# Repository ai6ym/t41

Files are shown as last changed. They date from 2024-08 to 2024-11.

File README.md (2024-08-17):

# T41-EP SDT Project Files

Hardware and software files for the T41-EP SDT as sold / distributed by [AI6YM](https://ai6ym.radio/t41-ep-sdt). These files are branched from [K9HZ's Repo](https://github.com/DRWJSCHMIDT/T41) and [G0ORX's Repo](https://github.com/g0orx/T41-EP) with some files from the [SoftwareControlledHamRadio Groups.IO](https://groups.io/g/SoftwareControlledHamRadio).

Changes present here are minor modifications made to enable automated SMD assembly, pre-programming of the Teensy and ATTiny, etc. Refinements to various BOMs (bill of materials) have been made to substitute parts which are unavailable or correct errors.

Software within this repository is licensed under GNU GPL v3. Hardware designs are licensed under TAPR OHL Version 1.0. In addition to these licenses the original creators of the T41, Albert F Peter (AC8GY) and Dr. Jack Purdum (W8TEE), have requested that any commercial use of the designs receive their written permission.

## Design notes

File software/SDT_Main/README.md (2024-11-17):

# Introduction

This repository hosts the code for the T41-EP Software Defined Transceiver (SDT). Originally designed by Al Peter-AC8GY and Jack Purdum-W8TEE, the T41-EP is a 20W, HF, 7 band, CW/SSB Software Defined Transceiver (SDT) with features not even found in commercial radios costing ten times as much (e.g., up to 192kHz spectrum display bandwidth, ALP CW decoder, Bode Plots). The T41-EP is a self-contain SDT that does not require an external PC, laptop, or tablet to use. Al and Jack wrote a book, available on [Amazon](https://a.co/d/drLsJlJ), describing the theory and operation of the T41-EP.

### Home on the web

The T41-EP is a fully open-source radio. This repository hosts the transceiver software. The hardware designs are hosted on Bill-K9HZ's [GitHub repository](https://github.com/DRWJSCHMIDT/T41/tree/main/T41_V012_Files_01-15-24). The primary forum for discussions on the T41-EP radio is on [Groups.io](https://groups.io/g/SoftwareControlledHamRadio/topics).

### Design philosophy

The EP stands for Experimenter's Platform because the T41-EP is designed around 5 small printed circuit boards (100mm x 100mm) that can be easily swapped for boards of your own design. Because the T41-EP project is completely Open Source, you have complete access to the C/C++ source code that controls the T41-EP as well as the KiCad design files, schematics, and Gerber files. 

### Hardware purchase

The latest version (V12.6) of the bare PCBs are available for less than $5 each on the [discussion forum](https://groups.io/g/SoftwareControlledHamRadio). If you prefer a partially-assembled kit,  Justin AI6YM sells them on his [website](https://ai6ym.radio/t41-ep-sdt/).

Kits for the prior hardware version (V11) were produced and sold by the [4SQRP club](http://www.4sqrp.com/T41main.php).

### Major software variants

There are three primary software forks for the T41-EP radio. Greg KF5N has produced the [T41 Extreme Experimenters Edition (T41EEE)](https://github.com/Greg-R/T41EEE) which implements innovative features but currently only supports V11 hardware. [Terrance KN6ZDE](https://github.com/tmr4/T41_SDR) has a fork that implements mouse and keyboard input, a beacon monitor, and has implemented new modes like NFM and some data modes.

This repository hosts the "official" vanilla fork for the [V12.6 hardware](https://github.com/DRWJSCHMIDT/T41/tree/main/T41_V012_Files_01-15-24). It merges the original software written by Jack and Al with the additional features written by [John Melton-G0ORX](https://github.com/g0orx/SDTVer050.0). We aspire to merge in changes and features implemented by others if they are supported by unmodified V12.6 hardware. You are encouraged to fork this repository, experiment, and submit pull requests if you develop a feature others will like! Your help tackling the list of [Issues](https://github.com/KI3P/SDTVer050.0/issues) would also be valuable.

# SDTVer050.2

This version has the following extra software features:

* Bearing plots
* Bode plots
* Kenwood TS-2000 CAT interface
* Built-in-test for I2C errors

The V12.6 hardware features currently supported in this version include:

* Shutdown routine using the ATTiny85 on the main board
* V12.6 BPF board
* K9HZ LPF board (band select only)
* G0ORX / K9HZ MCP23017 front panel and encoders
* IQ and power amp calibration

V12.6 hardware features that still need to be supported in software include:

* K9HZ LPF SWR meter
* K9HZ LPF transverter selection
* K9HZ LPF 100W amp selection
* K9HZ LPF antenna selection

# Compiling

To build this version configure Arduino IDE to use the [Teensyduino](https://www.pjrc.com/teensy/td_download.html) library, select the Teensy 4.1 board, and select the following build configuration options: 

* Tools->Optimize->Faster with LTO
* Tools->USB Type->Dual Serial
* Tools->CPU Speed->528 MHz

The memory Usage with these options set and both `G0ORX_FRONTPANEL` and `G0ORX_CAT` enabled should look something like:

```
   FLASH: code:274516, data:93624, headers:8684   free for files:7749640
   RAM1: variables:200864, code:256936, padding:5208   free for local variables:61280
   RAM2: variables:454272  free for malloc/new:70016
```

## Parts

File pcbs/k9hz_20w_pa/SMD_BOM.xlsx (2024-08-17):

 |  |  | xxxx xxxx xxxxx xxPCS BOM (Sample Bill of Materials)
Item # | *Designator | *Qty | Manufacturer | *Mfg Part # | Description / Value | *Package/Footprint | Type | Your Instructions / Notes
1 | C1 | 1 | KEMET | C1206C470K5GACTU | CAP CER 47pf 50V X7R 1206 | 1206 | SMD
2 | C2, C3, C4, C5, C9, C10, C12, C13, C14, C15, C17, C20, C21, C23, C25 | 15 | KEMET | C1206C104K5RAC7867 | CAP CER 0.1UF 50V X7R 1206 | 1206 | SMD
3 | C7, C8, C16, C19 | 4 | KEMET | C1206C103K5RACTM | CAP CER 0.01UF 50V X7R 1206 | 1206 | SMD
4 | C18 | 1 | Yageo | CC1206MRY5V9BB105 | CAP CER 1uF 50V Y5V 1206 20% | 1206 | SMD
5 | C6, C11 | 2 | Samsung Electro-Mechanics | CL31A106KBHNNNE | CAP CER 10 UF 50V X7R 1206 | 1206 | SMD
6 | C22 | 1 | KEMET | EEV107M035A9HAA | Alum CAP SMD 35V 100uF 20% | 9H | SMD
7 | Q1 | 1 | Infineon Technologies | IRLML9301TRPBF | IRLML9301TRPBF | SOT-23-3 | SMD
8 | Q4 | 1 | Comchip Technology | MMBT3904-HF | MMBT3904 SOT-23 | SOT-23-3 | SMD
9 | R10, R11 | 2 | Yageo | RC1206FR-075R1L | SMD 5.1 Ohms 250 mW 1206 1% | 1206 | SMD
10 | R1 | 1 | Yageo | RC1206FR-076R8L | SMD 6.8 Ohms 250 mW 1206 1% | 1206 | SMD
11 | R4, R5 | 2 | SEI Stackpole | RMCF1206FT100R | SMD 100 Ohms 250 mW 1206 1% | 1206 | SMD
12 | R2, R3 | 2 | Vishay / Dale | CRCW1206680RFKEAC | SMD 680 Ohms 250 mW 1206 1% | 1206 | SMD
13 | R12, R13 | 2 | SEI Stackpole | RMCF1206FT750R | SMD 750 Ohms 250 mW 1206 1% | 1206 | SMD
14 | R8, R9, R14, R15, R16, R17, R18, R19, R23 | 9 | Yageo | RC1206FR-071KL | SMD 1000 Ohms 250 mW 1206 1% | 1206 | SMD
15 | R6, R7 | 2 | Bourns | CR1206-FX-2201ELF | SMD 2.2K Ohms 250 mW 1206 1% | 1206 | SMD
16 | R22, R24 | 2 | Welwyn Components / TT Electronics | WCR1206-10KFA | SMD 10K Ohms 250 mW 1206 1% | 1206 | SMD
17 | U1 | 1 | Texas Instruments | OPA2674ID | OPA2674ID | SOIC-8 | SMD
18 | U2 | 1 | STMicroelectronics | L78L09ACUTR | L78L09ACUTR | SOT-89 | SMD
Need a quick and accurante quote? Need an efficient production? Please read SMT Ordering Necessary Files & Info in 1 minute. Thank you very much! (https://www.pcbway.com/smt_ordering_guide.html)
Click for Instructions on How to Create a BOM (https://www.pcbway.com/blog/PCB_Assembly/How_to_Build_a_BOM__Bill_Of_Materials_.html)

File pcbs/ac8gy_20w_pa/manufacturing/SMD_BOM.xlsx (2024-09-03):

 |  |  | xxxx xxxx xxxxx xxPCS BOM (Sample Bill of Materials)
Item # | *Designator | *Qty | Manufacturer | *Mfg Part # | Description / Value | *Package/Footprint | Type | Your Instructions / Notes
1 | C1, C2, C3, C5, C6, C7, C8, C9, C10, C12, C24, C101, C102, C104, C105, C107, C108, C109, C110, C111, C112, C201, C202, C204, C206, C208, C209, C300, C302 | 29 | KEMET | C1206C104K5RAC7800 | CAP CER 0.1UF 50V X7R 1206 | 1206 | SMD
2 | L1 | 1 | Abracon LLC | AIML-1206-R18K-T | FIXED IND 180NH 250MA 300MOHM SM | 1206 | SMD
3 | L2, L101, L103, L201, L204 | 5 | Eaton - Electronics Division | MCLA3216V1-2R2-R | FIXED IND 2.2UH 50MA 500MOHM SMD | 1206 | SMD
4 | L102, L104, L202, L203 | 4 | Vishay / Dale | ILSB1206ERR33K | FIXED IND 330NH 250MA 600MOHM SMD | 1206 | SMD
5 | R101, R103 | 2 | TE Connectivity Passive Product | CRG1206F100R | RES SMD 100 OHM 1% 1/4W 1206 | 1206 | SMD
6 | R106, R107 | 2 | Stackpole Electronics Inc | RMCF1206FT1K10 | RES 1.1K OHM 1% 1/4W 1206 | 1206 | SMD
7 | R201, R204 | 2 | TE Connectivity Passive Product | CRGCQ1206F56R | RES 56 OHM 1% 1/4W 1206 | 1206 | SMD
8 | R303 | 1 | Stackpole Electronics Inc | RMCF1206FT470R | RES 470 OHM 1% 1/4W 1206 | 1206 | SMD
9 | R306 | 1 | TE Connectivity Passive Product | CRG1206F220R | RES 220 OHM 1% 1/4W 1206 | 1206 | SMD
10 | C4 | 1 | Yageo | CC1206KRX7R9BB391 | CAP CER 390PF 50V C0G/NP0 1206 | 1206 | SMD
11 | C103, C106, C203, C207 | 4 | Samsung Electro-Mechanics | CL31B474KBHNNNE | CAP CER 0.47UF 50V X7R 1206 | 1206 | SMD
12 | C205 | 1 | Würth Elektronik | 885012008040 | CAP CER 33PF 50V C0G/NP0 1206 | 1206 | SMD
13 | C11, C301 | 2 | Chemi-Con | EMVE160ARA101MF55G | CAP ALUM 100UF 20% 16V 4.3X4.3 SMD | 6.3x6.6mm | SMD
14 | R1 | 1 | Stackpole Electronics Inc | RMCF1206FT4K70 | RES 4.7K OHM 1% 1/4W 1206 | 1206 | SMD
15 | R2 | 1 | Rohm Semiconductor | KTR18EZPF5101 | RES SMD 5.1K OHM 1% 1/4W 1206 | 1206 | SMD
16 | R3 | 1 | Stackpole Electronics Inc | RMCF1206FT200R | RES 200 OHM 1% 1/4W 1206 | 1206 | SMD
17 | R4, R16, R304 | 3 | Stackpole Electronics Inc | RMCF1206FT150R | RES 150 OHM 1% 1/4W 1206 | 1206 | SMD
18 | R5 | 1 | Stackpole Electronics Inc | RMCF1206FT3K30 | RES 3.3K OHM 1% 1/4W 1206 | 1206 | SMD
19 | R6 | 1 | Stackpole Electronics Inc | RMCF1206FT5K60 | RES 5.6K OHM 1% 1/4W 1206 | 1206 | SMD
20 | R7 | 1 | Bourns | CR1206-FX-1201ELF | RES 1.2K OHM 1% 1/4W 1206 | 1206 | SMD
21 | R8 | 1 | Stackpole Electronics Inc | RMCF1206JT68R0 | RES 68 OHM 5% 1/4W 1206 | 1206 | SMD
22 | R9 | 1 | Stackpole Electronics Inc | RMCF1206FT3K00 | RES 3K OHM 1% 1/4W 1206 | 1206 | SMD
23 | R10 | 1 | Stackpole Electronics Inc | RMCF1206JT680R | RES 680 OHM 5% 1/4W 1206 | 1206 | SMD
24 | R11, R13 | 2 | Stackpole Electronics Inc | RMCF1206FT24K0 | RES 24K OHM 1% 1/4W 1206 | 1206 | SMD
25 | R12, R15, R301, R302 | 4 | Stackpole Electronics Inc | RMCF1206FT10K0 | RES 10K OHM 1% 1/4W 1206 | 1206 | SMD
26 | R14 | 1 | Stackpole Electronics Inc | RMCF2512JT47R0 | RES 47 OHM 1% 1/4W 1206 | 1206 | SMD
27 | R17 | 1 | Rohm Semiconductor | KTR18EZPF37R4 | RES 37.4 OHM 1% 1/4W 1206 | 1206 | SMD
28 | R19 | 1 | Yageo | RC1206FR-075K49L | RES 5.49K OHM 1% 1/4W 1206 | 1206 | SMD
Need a quick and accurante quote? Need an efficient production? Please read SMT Ordering Necessary Files & Info in 1 minute. Thank you very much! (https://www.pcbway.com/smt_ordering_guide.html)
Click for Instructions on How to Create a BOM (https://www.pcbway.com/blog/PCB_Assembly/How_to_Build_a_BOM__Bill_Of_Materials_.html)

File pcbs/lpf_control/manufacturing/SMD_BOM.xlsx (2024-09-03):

 |  |  | xxxx xxxx xxxxx xxPCS BOM (Sample Bill of Materials)
Item # | *Designator | *Qty | Manufacturer | *Mfg Part # | Description / Value | *Package/Footprint | Type | Your Instructions / Notes
1 | C15 | 1 | KEMET | C1206C102K5RAC | 1000pF 50V | 1206 | SMD
2 | C24, C25 | 2 | KEMET | C1206C301F1HACAUTO | 300 pF 50V | 1206 | SMD
3 | C14, C16 | 2 | KEMET | C1206C162K3HACTU | 1600 pF 50V | 1206 | SMD
4 | L1, L2 | 2 | Vishay / Dale | ILSB1206ER3R3K | 3.3uH | 1206 | SMD
5 | C1, C2, C3, C4, C5, C6, C7, C8, C10, C11, C12, C13, C17, C18, C20, C21, C22, C23, C128, C129, C130, C138, C140, C141, C148, C137, C139, C150, C151, C152 | 30 | KEMET | C1206C104K5RACTU | 0.1uF 50V | 1206 | SMD
6 | C19 | 1 | Kyocera AVX | 12065C153KAT2A | 15nF 50V | 1206 | SMD
7 | C132, C133, C135, C136, C146 | 5 | Samsung Electro-Mechanics | CL31B105KBHNNNE | 1uF 50V SMD 1206 Capacitor | 1206 | SMD
8 | C143, C145 | 2 | KEMET | C1206C106K4PACTU | 10uF 16V SMD 1206 Capacitor | 1206 | SMD
9 | L36, L37, L39, L41 | 4 | Laird Perfomance Materials | HZ1206E601R-10 | FB SMD 1206 600 Ohm 1A | 1206 | SMD
10 | L200 | 1 | Murata Electronics | 1264EY-100M=P3 | 10uH 20% Power Inductor | 2424 | SMD
11 | R7 | 1 | Vishay / Dale | CRCW120610K0FKEA | 10K Ohm SMD 1206 Resistor | 1206 | SMD
12 | R1, R2, R3, R12, R14, R15 | 6 | Bourns | CR1206-JW-222ELF | 2.2K Ohm SMD 1206 Resistor | 1206 | SMD
13 | U1, U3, U7, U8, U21 | 5 | MACOM | MASWSS0179TR-3000 | MASWSS0179 | SOT-26 | SMD
14 | U2 | 1 | Toshiba | 74HC237D(BJ) | 74HC237 | SOIC-16 | SMD
15 | U4, U9, U10 | 3 | Texas Instruments | ULN2803CDWR | ULN2803A | SOIC-20 | SMD
16 | U5, U6, U22 | 3 | Texas Instruments | SN74LVC1G04DCKR | 74LVC1G04DCKR | SC70-5 | SMD
17 | U12 | 1 | Texas Instruments | CD74HC4514M96 | CD74HC4514M96 | SOIC-24 | SMD
18 | U15 | 1 | Microchip Technology | MCP23017-E/SO | MCP23017_SO | SOIC-28 | SMD
19 | U18 | 1 | Microchip Technology | TC4428ACOA | TC4428 | SOIC-8 | SMD
20 | C144, C155 | 2 | KEMET | C1206C103K5RAC7210 | 10nF 50V | 1206 | SMD
21 | C147, C154 | 2 | KEMET | C1206C100J5GAC | 10pF 50V | 1206 | SMD
22 | L38, L40, L42, L43 | 4 | Abracon | AISC-1206-22NJ-T | 22nH SMD 1206 Inductor | 1206 | SMD
23 | R13, R21 | 2 | Yageo | RC1206FR-0752R3L | 52.3 Ohm SMD 1206 Resistor | 1206 | SMD
24 | R16, R18, R24, R25 | 4 | Vishay / Dale | CRCW120654R9FKEA | 54.9 Ohm SMD 1206 Resistor | 1206 | SMD
25 | R17, R22 | 2 | Vishay / Dale | CRCW1206499RFKEB | 499 Ohm SMD 1206 Resistor | 1206 | SMD
26 | U14, U19 | 2 | Analog Devices | AD8307ARZ-RL7 | AD8307 | SOIC-8 | SMD
27 | U17 | 1 | Texas Instruments | REF3440IDBVR | REF3440IDBVR | SOT-23-6 | SMD
28 | U20 | 1 | Analog Devices | AD7991YRJZ-0500RL7 | AD7991YRJZ | SOT-23-8 | SMD
Need a quick and accurante quote? Need an efficient production? Please read SMT Ordering Necessary Files & Info in 1 minute. Thank you very much! (https://www.pcbway.com/smt_ordering_guide.html)
Click for Instructions on How to Create a BOM (https://www.pcbway.com/blog/PCB_Assembly/How_to_Build_a_BOM__Bill_Of_Materials_.html)

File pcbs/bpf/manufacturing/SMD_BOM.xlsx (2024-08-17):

 |  |  | xxxx xxxx xxxxx xxPCS BOM (Sample Bill of Materials)
Item # | *Designator | *Qty | Manufacturer | *Mfg Part # | Description / Value | *Package/Footprint | Type | Your Instructions / Notes
1 | C2, C4, C5, C6, C7, C8, C9, C10, C11, C12, C13, C14, C15, C16, C17, C18, C19, C20, C21, C22, C23, C24, C25, C26, C27 C41, C90, C91, C97, C98, C100, C101,C107, C108, C190, C191, C197, C198, C200, C201, C207, C208, C290, C291, C297, C298, C300, C301, C307, C308, C400, C401, C407, C408, C500, C501, C507, C508, C600, C601, C607, C608, C700, C701 | 64 | KEMET | C1206C104K5RACTU | 0.1uF 50V SMD 1206 Capacitor | 1206 | SMD
2 | C94 | 1 | Kyocera AVX | 12061C562JAT2A | 5.6nF 50V | 1206 | SMD
3 | C104 | 1 | Kyocera AVX | 12062A302JAT2A | 3.0nF 50V | 1206 | SMD
4 | C194 | 1 | Kyocera AVX | 12065C242JAT4A | 2.4nF 50V | 1206 | SMD
5 | C204 | 1 | KEMET | C1206C202K5HACTU | 2.0nF 50V | 1206 | SMD
6 | C102, C106, C294 | 3 | KEMET | C1206C182K1RACTU | 1.8nF 50V | 1206 | SMD
7 | C92, C92b1, C96, C96b1 | 4 | KEMET | C1206C162K3HACTU | 1.6nF 50V | 1206 | SMD
8 | C304 | 1 | KEMET | C1206C132J1GACTU | 1.3nF 50V | 1206 | SMD
9 | C192, C196, C202, C206 | 4 | KEMET | C1206C122J5GACTU | 1.2nF 50V | 1206 | SMD
10 | C292, C296 | 2 | KEMET | C1206C102K5RACTU | 1.0nF 50V | 1206 | SMD
11 | C302, C306 | 2 | KEMET | C1206C751J5GACTU | 750pF 50V | 1206 | SMD
12 | C404 | 1 | Walsin | 1206B681K500CT | 680pF 50V | 1206 | SMD
13 | C504 | 1 | KEMET | C1206C511J5HACAUTO | 510pF 50V | 1206 | SMD
14 | C402, C406 | 2 | KEMET | C1206C391K1HACTU | 390pF 50V | 1206 | SMD
15 | C93, C95 | 2 | KEMET | C1206C331J5GACTU | 330pF 50V | 1206 | SMD
16 | C103, C105, C502, C506 | 4 | KEMET | C1206C301J5GACTU | 300pF 50V | 1206 | SMD
17 | C93b1, C95b1 | 2 | Kyocera AVX | 12061A251FAT2A | 250pF 50V | 1206 | SMD
18 | C602, C606 | 2 | KEMET | C1206C241J5GACTU | 240pF 50V | 1206 | SMD
19 | C604b1 | 1 | KEMET | C1206C201J5HACAUTO | 200pF 50V | 1206 | SMD
20 | C203, C205, C604 | 3 | KEMET | C1206C181J1GACTU | 180pF 50V | 1206 | SMD
21 | C193b1, C195b1 | 2 | KEMET | C1206C121J5GAC | 120pF 50V | 1206 | SMD
22 | C94b1, C194b1, C294b1 | 3 | KEMET | C1206C101K1GACTU | 100pF 50V | 1206 | SMD
23 | C303, C305, C193, C195 | 4 | Kyocera AVX | 12065A750JAT2A | 75pF 50V | 1206 | SMD
24 | C293, C295 | 2 | KEMET | C1206C680J5HACTU | 68pF 50V | 1206 | SMD
25 | C403, C405 | 2 | KEMET | C1206C510J5HACTU | 51pF 50V | 1206 | SMD
26 | C503, C505 | 2 | KEMET | C1206C430J5GACTU | 43pF 50V | 1206 | SMD
27 | C603, C605 | 2 | KEMET | C1206C130F1HACTU | 13pF 50V | 1206 | SMD
28 | R1, R2, R3, R4, R5, R6, R7, R8 | 8 | Bourns | CR1206-FX-2201ELF | 2.2K Ohm SMD 1206 Resistor | 1206 | SMD
29 | D1, D2, D3, D4 | 4 | Nexperia | BAS70H,115 | BAS70H,115 Diodes | SOD-123F-2 | SMD
30 | L1 | 1 | Murata Electronics | 1264EY-100M=P3 | 10uH SMD Incurtor | 2424 | SMD
31 | L2 | 1 | Laird Performance Materials | HZ1206E601R-10 | Ferrite Bead SMD 1206 600 Ohm | 1206 | SMD
32 | U35 | 1 | Microchip Technology | MCP23017-E/SO | MCP23017-E/SO | SOIC-28 | SMD
33 | U1, U3, U4, U6, U7, U9, U10, U12, U13, U15, U16, U18, U19, U21, U24, U25, U27, U28, U30, U31, U36 | 21 | MACOM | MASWSS0179TR-3000 | MASWS0179 | SOT-26 | SMD
34 | U2, U5, U8, U11, U14, U17, U20, U23, U26, U29, U37 | 11 | Texas Instruments | SN74LVC1G04DCKR | 74LVC1G04GW | SC70-5 | SMD
Need a quick and accurante quote? Need an efficient production? Please read SMT Ordering Necessary Files & Info in 1 minute. Thank you very much! (https://www.pcbway.com/smt_ordering_guide.html)
Click for Instructions on How to Create a BOM (https://www.pcbway.com/blog/PCB_Assembly/How_to_Build_a_BOM__Bill_Of_Materials_.html)

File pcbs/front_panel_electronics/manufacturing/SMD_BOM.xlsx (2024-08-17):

 |  |  | xxxx xxxx xxxxx xxPCS BOM (Sample Bill of Materials)
Item # | *Designator | *Qty | Manufacturer | *Mfg Part # | Description / Value | *Package/Footprint | Type | Your Instructions / Notes
1 | C1, C2 | 2 | KEMET | C1206C104K5RACTU | 0.1uF 50V 1206 SMD Capacitor | 1206 | SMD
2 | R1, R2,R3,R4 | 4 | Bourns | CR1206-FX-2201ELF | 2.2K Ohm 1206 SMD Resistor | 1206 | SMD
3 | R5, R6 | 2 | Bourns | CR1206-JW-331ELF | 330 Ohm 1206 SMD Resistor | 1206 | SMD
4 | U1, U2 | 2 | Microchip Technology | MCP23017-E/SO | MCP23017SO SOIC-28 | SOIC-28 | SMD
Need a quick and accurante quote? Need an efficient production? Please read SMT Ordering Necessary Files & Info in 1 minute. Thank you very much! (https://www.pcbway.com/smt_ordering_guide.html)
Click for Instructions on How to Create a BOM (https://www.pcbway.com/blog/PCB_Assembly/How_to_Build_a_BOM__Bill_Of_Materials_.html)

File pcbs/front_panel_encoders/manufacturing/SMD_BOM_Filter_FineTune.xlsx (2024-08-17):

 |  |  | xxxx xxxx xxxxx xxPCS BOM (Sample Bill of Materials)
Item # | *Designator | *Qty | Manufacturer | *Mfg Part # | Description / Value | *Package/Footprint | Type | Your Instructions / Notes
1 | C1, C2, C3, C4, C5, C6 | 6 | KEMET | C1206C104K5RACTU | 0.1uF 50V 1206 SMD Capacitor | 1206 | SMD
2 | R3, R5, R7, R8 | 4 | Vishay / Dale | CRCW12060000Z0EAC | 0 Ohm SMD 1206 Resistor | 1206 | SMD
Need a quick and accurante quote? Need an efficient production? Please read SMT Ordering Necessary Files & Info in 1 minute. Thank you very much! (https://www.pcbway.com/smt_ordering_guide.html)
Click for Instructions on How to Create a BOM (https://www.pcbway.com/blog/PCB_Assembly/How_to_Build_a_BOM__Bill_Of_Materials_.html)

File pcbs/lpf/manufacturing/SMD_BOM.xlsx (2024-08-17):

 |  |  | xxxx xxxx xxxxx xxPCS BOM (Sample Bill of Materials)
Item # | *Designator | *Qty | Manufacturer | *Mfg Part # | Description / Value | *Package/Footprint | Type | Your Instructions / Notes
1 | C70 | 1 | Murata Electronics | GQM2195C2E140JB12D | 14pF 200V | 0805 | SMD
2 | C63, C69 | 2 | YAGEO | CC1206JKNPOCBN270 | 27pF 200V | 1206 | SMD
3 | C65 | 1 | YAGEO | CC1206JKNPOCBN330 | 33pF 200V | 1206 | SMD
4 | C71 | 1 | KEMET | C1206C390J2GACTU | 39 pF 200V | 1206 | SMD
5 | C60, C62, C64 | 3 | YAGEO | CC1206JRNPOABN470 | 47pF 200V | 1206 | SMD
6 | C57, C75 | 2 | KEMET | C1206C560J2GACTU | 56pF 200V | 1206 | SMD
7 | C39, C67, C100 | 3 | Kyocera AVX | 12062A600FAT2A | 60pF 200V | 1206 | SMD
8 | C66, C68 | 2 | KEMET | C1206C680J2GACTU | 68pF 200V | 1206 | SMD
9 | C24, C35, C41, C53, C72, C85, C90, C105 | 8 | KEMET | C1206C820J2GACTU | 82pF 200V | 1206 | SMD
10 | C51, C82 | 2 | Cal-Chip Electronics Inc. | CHV1206N500910JCT | 91pF 200V | 1206 | SMD
11 | C32, C38, C52, C56, C58, C74, C76, C94, C99 | 9 | Kyocera AVX | 12062A101JAT2A | 100pF 200V | 1206 | SMD
12 | C37, C98 | 2 | Kyocera AVX | 12062A121JAT2A | 120pF 200V | 1206 | SMD
13 | C27, C28, C33, C36, C42, C61, C83, C95, C97, C102, C104 | 11 | YAGEO | CC1206JRNPOABN151 | 150pF 200V | 1206 | SMD
14 | C50, C81 | 2 | Kyocera AVX | 12062A181JAT2A | 180pF 200V | 1206 | SMD
15 | C34, C49, C80, C96 | 4 | Kyocera AVX | 12062A221JAT2A | 220pF 200V | 1206 | SMD
16 | C25, C43, C44, C48, C54, C55, C59, C73, C77, C79, C87, C88, C103 | 13 | Kyocera AVX | 12062A331JAT2A | 330pF 200V | 1206 | SMD
17 | C26, C101 | 2 | Kyocera AVX | 12062A391JAT2A | 390pF 200V | 1206 | SMD
18 | C30, C40, C47, C78, C89, C92 | 6 | Yageo | CC1206JRNPOABN471 | 470pF 200V | 1206 | SMD
19 | C31, C93 | 2 | KEMET | C1206C561J2GACTU | 560pF 200V | 1206 | SMD
20 | C46, C86 | 2 | Kyocera AVX | 12062A122JAT2A | 1200pF 200V | 1206 | SMD
21 | C29, C91 | 2 | YAGEO | CC1206JRNPOABN152 | 1500pF 200V | 1206 | SMD
22 | C45, C84 | 2 | Kyocera AVX | 12062C222JAT2A | 2200pF 200V | 1206 | SMD
23 | C106, C107, C108, C109, C110, C111, C112, C113, C114, C115, C116, C117, C118, C119, C120, C121, C122, C123, C124, C125, C126, C127, C157, C158 | 24 | KEMET | C1206C104K5RACTU | 0.1uF 50V | 1206 | SMD
Need a quick and accurante quote? Need an efficient production? Please read SMT Ordering Necessary Files & Info in 1 minute. Thank you very much! (https://www.pcbway.com/smt_ordering_guide.html)
Click for Instructions on How to Create a BOM (https://www.pcbway.com/blog/PCB_Assembly/How_to_Build_a_BOM__Bill_Of_Materials_.html)

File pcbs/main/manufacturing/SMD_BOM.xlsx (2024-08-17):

 |  |  | xxxx xxxx xxxxx xxPCS BOM (Sample Bill of Materials)
Item # | *Designator | *Qty | Manufacturer | *Mfg Part # | Description / Value | *Package/Footprint | Type | Your Instructions / Notes
1 | C2, C3, C8, C9, C10, C11, C13, C14, C16, C19, C20, C23, C24, C26, C31 | 15 | KEMET | C1206C104K5RACTU | 0.1uF 50V SMD 1206 Ceramic Capacitor | 1206 | SMD
2 | C32, C34 | 2 | KEMET | C1206C222K5RAC | 2.2nF 50V SMD 1206 Capacitor | 1206 | SMD
3 | C28, C29 | 2 | KEMET | C1206C225K5R | 2.2uF 25V SMD 1206 Capacitor | 1206 | SMD
4 | C4, C12, C15, C17, C18, C21, C22, C25, C27, C30, C33 | 11 | KEMET | C1206C106K4P | 10uF 16V SMD 1206 Capacitor | 1206 | SMD
5 | D2, D3, D4 | 3 | Dialight | 599-0220-007F | LED Diodes SMD; Colors to suit | 1206 | SMD
6 | L1, L2, L3 | 3 | Murata Electronics | 1264EY-100M=P3 | Inductor 10uH 20% | 2424 | SMD
7 | R6, R11, R12 | 3 | Bourns | CR1206-FX-1000ELF | 100 Ohm SMD 1206 Resistor | 1206 | SMD
8 | R15 | 1 | YAGEO | RC1206JR-07150RL | 150 Ohm SMD 1206 Resistor | 1206 | SMD
9 | R4, R5 | 2 | TE Connectivity / Holsworthy | CRGCQ1206J220R | 220 Ohm SMD 1206 Resistor | 1206 | SMD
10 | R8, R9, R14 | 3 | SEI Stackpole | RMCF1206FT330R | 330 Ohm SMD 1206 Resistor | 1206 | SMD
11 | R10, R13 | 2 | Vishay / Dale | CRCW1206470RJNEAC | 470 Ohm SMD 1206 Resistor | 1206 | SMD
12 | R7 | 1 | Vishay / Dale | CRCW12062K20JNEAC | 2.2K Ohm SMD 1206 Resistor | 1206 | SMD
13 | U5 | 1 | Texas Instruments | PCM5102APWR | PCM5102APW Stereo DAC TSSOP-20 |  | SMD
14 | U6 | 1 | Texas Instruments | PCM1808PWR | PCM1808PWR Stereo ADC TSSOP-14 |  | SMD
15 | C5 | 1 | Samsung Electro-Mechanics | CL31B105KBHNNNE | 1.0uF 50V SMD 1206 Capacitor | 1206 | SMD
16 | D1 | 1 | Diodes Incorporated | S1A-13-F | S1A-13-F Diode or equivalent (1N4001) |  | SMD
17 | R3 | 1 | Vishay / Dale | CRCW12061K00JNEAC | 1K Ohm SMD 1206 Resistor | 1206 | SMD
18 | R1, R2 | 2 | Vishay / Dale | CRCW120610K0FKEB | 10K Ohm SMD 1206 Resistor | 1206 | SMD
Need a quick and accurante quote? Need an efficient production? Please read SMT Ordering Necessary Files & Info in 1 minute. Thank you very much! (https://www.pcbway.com/smt_ordering_guide.html)
Click for Instructions on How to Create a BOM (https://www.pcbway.com/blog/PCB_Assembly/How_to_Build_a_BOM__Bill_Of_Materials_.html)

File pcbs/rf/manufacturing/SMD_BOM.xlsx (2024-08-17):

 |  |  | xxxx xxxx xxxxx xxPCS BOM (Sample Bill of Materials)
Item # | *Designator | *Qty | Manufacturer | *Mfg Part # | Description / Value | *Package/Footprint | Type | Your Instructions / Notes
1 | C1, C3, C11, C12, C14, C32, C35, C36, C39, C41, C42, C48, C51, C57, C60, C67, C71 | 17 | Kyocera AVX | 12065D106KAT2A | 10uF 50V SMD 1206 Capacitor | 1206 | SMD
2 | C2, C9, C15, C24 | 4 | Samsung Electro-Mechanics | CL31B105KBHNNNE | 1uF 50V SMD 1206 Capacitor | 1206 | SMD
3 | C4, C10, C17, C28, C37, C54 | 6 | KEMET | C1206C103K5RAC7210 | 10nF 50V SMD 1206 Capacitor | 1206 | SMD
4 | C5, C21 | 2 | Kyocera AVX | 12065C101KAT2A | 100pF 50V SMD 1206 Capacitor | 1206 | SMD
5 | C8, C19 | 2 | Walsin | 1206B181K160CT | 180pF 50V SMD 1206 Capacitor | 1206 | SMD
6 | C6, C7, C13, C16, C18, C20, C22, C23, C25, C26, C27, C29, C30, C31, C40, C43, C45, C47, C49, C52, C53, C55, C56, C58, C59, C61, C62, C63, C64, C65, C66, C68, C70, C72, C73, C80 | 36 | KEMET | C1206C104K5RACTU | 0.1uF 50V SMD 1206 Capacitor | 1206 | SMD
7 | C33, C46 | 2 | KEMET | C1206C222K5RAC | 2.2nF 50V SMD 1206 Capacitor | 1206 | SMD
8 | C34, C38, C44, C50 | 4 | Kyocera AVX | 12065C204KAT4A | 0.2uF 50V SMD 1206 Capacitor | 1206 | SMD
9 | L1, L2, L3, L5, L6, L7, L8, L9, L107 | 9 | Laird Performance Materials | HZ1206E601R-10 | FB SMD 1206 600 Ohm 1A | 1206 | SMD
10 | L4, L10 | 2 | Murata Electronics | LQM31PN1R5M00L | 1.5uH SMD 1206 Inductor | 1206 | SMD
11 | L11, L12, L13 | 3 | Murata Electronics | 1264EY-100M=P3 | 10uH 20% SMD Inductor | 6.3mm x 6.3mm | SMD
12 | R1, R13 | 2 | Panasonic | ERA-8AEB202V | 2K Ohm SMD 1206 Resistor | 1206 | SMD
13 | R2, R3, R5, R6, R10, R11, R17, R18 | 8 | Bourns | CR1206-JW-512ELF | 5.1K Ohm SMD 1206 Resistor | 1206 | SMD
14 | R4, R8, R16, R22, R54 | 5 | Bourns | CR1206-FX-1000ELF | 100 Ohm SMD 1206 Resistor | 1206 | SMD
15 | R7, R9, R12, R20, R21, R23, R24, R28, R30, R39, R44, R47, R53, R55 | 14 | Bourns | CR1206-JW-103ELF | 10K Ohm SMD 1206 Resistor | 1206 | SMD
16 | R14 | 1 | Vishay / Dale | CRCW120636R5FKEA | 36.5 Ohm SMD 1206 Resistor | 1206 | SMD
17 | R15, R19 | 2 | Bourns | CR1206-FX-5100ELF | 510 Ohm SMD 1206 Resistor | 1206 | SMD
18 | R25, R29, R32, R36, R41, R46 | 6 | Bourns | CR1206-FX-1002ELF | 10K Ohm 1% SMD 1206 Resistor | 1206 | SMD
19 | R26, R34, R49, R50, R51, R52, R60, R61, R62, R63 | 10 | Vishay / Dale | CRCW12062K20JNEAC | 2.2K Ohm SMD 1206 Resistor | 1206 | SMD
20 | R27, R33, R38, R43 | 4 | Vishay / Dale | CRCW120649R9FKEAC | 49.9 Ohm 1% SMD 1206 Resistor | 1206 | SMD
21 | R31, R45 | 2 | Bourns | CR1206-FX-2201ELF | 2.2K Ohm 1% SMD 1206 Resistor | 1206 | SMD
22 | R35, R37 | 2 | Vishay / Dale | CRCW12063K30FKEA | 3.3K Ohm SMD 1206 Resistor | 1206 | SMD
23 | R40, R42 | 2 | Vishay / Dale | CRCW12060000Z0EAC | 0 Ohm SMD 1206 Resistor | 1206 | SMD
24 | R48, R73 | 2 | Vishay / Dale | CRCW1206100KFKEAC | 100K Ohm SMD 1206 Resistor | 1206 | SMD
25 | R56 | 1 | Bourns | CR1206-FX-1801ELF | 1.8K Ohm SMD 1206 Resistor | 1206 | SMD
26 | R57 | 1 | Bourns | CR1206-FX-3300ELF | 330 Ohm SMD 1206 Resistor | 1206 | SMD
27 | R58 | 1 | Bourns | CR1206-FX-5102ELF | 51K Ohm SMD 1206 Resistor | 1206 | SMD
28 | R59 | 1 | Bourns | CR1206-FX-1201ELF | 1.2K Ohm SMD 1206 Resistor | 1206 | SMD
29 | U1, U4 | 2 | Texas Instruments | SN74CBTLV3253DR | 74CBTLV3253DR in SOIC-16 | 16-SOIC | SMD
30 | U2 | 1 | Mini-Circuits | PSA-8A+ | PSA-8A+ | CA1389 | SMD
31 | U3, U12 | 2 | pSemi | PE4312C-Z | PE4312 (or DAT-31R5A-PP+) | QFN-20 | SMD
32 | U5, U10 | 2 | Texas Instruments | SN74LVC1G04DCKR | 74LVC1G04DCKR | SC70-5 | SMD
33 | U6, U8, U106, U107 | 4 | Texas Instruments | MC33078DR | MC33078 | SOIC-8 | SMD
34 | U16 | 1 | Texas Instruments | LM358BIDR | LM358B | SOIC-8 | SMD
35 | U7, U9 | 2 | Macom | MASWSS0179TR-3000 | MASWSS0179 | SOT-26 | SMD
36 | U11 | 1 | Skyworks Solutions, Inc. | SI5351A-B-GT | Si5351A-B-GT | MSOP-10 | SMD
37 | U13 | 1 | Mini-Circuits | MAR-3SM+ | MAR-3SM+ | WW107 | SMD
38 | U17 | 1 | Texas Instruments | LM317LIDR | LM317LIDR | SOIC-8 | SMD
39 | U21 | 1 | Microchip Technology | MCP23017-E/SO | MCP23017_SO | SOIC-28 | SMD
40 | TR1 | 1 | Mini-Circuits | ADT1-1+ | ADT1-1+ | CD542 | SMD
41 | TR2 | 1 | Mini-Circuits | ADT2-1T+ | ADT2-1T+ | CD542 | SMD
42 | Y1 | 1 | ECS | ECS-TXO53-S3-33-250-BN-TR | ECS-TX053-S3 | 5.0 x 3.2 mm | SMD
43 | Y2 | 1 | ECS | ECS-250-18-5PX-GM-TR | 25MHz | SPX | SMD
Need a quick and accurante quote? Need an efficient production? Please read SMT Ordering Necessary Files & Info in 1 minute. Thank you very much! (https://www.pcbway.com/smt_ordering_guide.html)
Click for Instructions on How to Create a BOM (https://www.pcbway.com/blog/PCB_Assembly/How_to_Build_a_BOM__Bill_Of_Materials_.html)

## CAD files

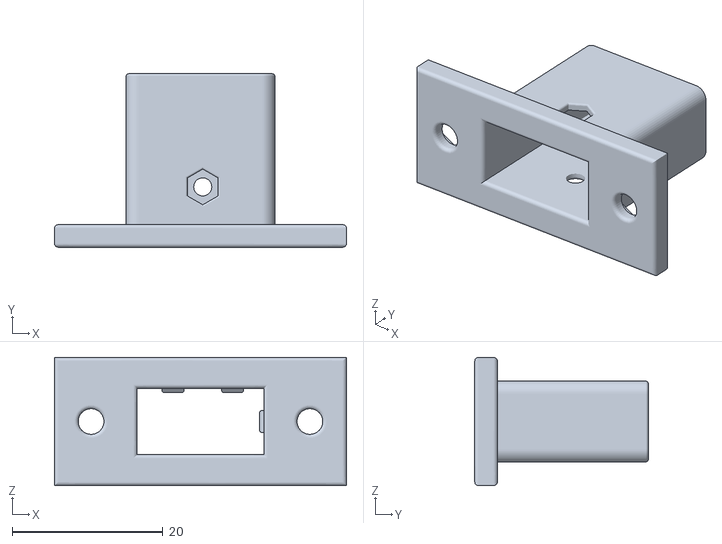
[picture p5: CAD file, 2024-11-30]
enclosure/manufacturing/Powerpole Panel Mount.stl
38.7 x 23.0 x 17.0

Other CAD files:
enclosure/Powerpole Panel Mount.f3d

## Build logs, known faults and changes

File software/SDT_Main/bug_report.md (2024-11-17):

---
name: Bug report
about: Create a report to help us improve
title: ''
labels: ''
assignees: ''

---

**Describe the bug**
A clear and concise description of what the bug is.

**To Reproduce**
Steps to reproduce the behavior:
1. Press button '...'
2. Spin dial '....'
3. See error

**Expected behavior**
A clear and concise description of what you expected to happen.

**Affected radio board**
Which board or system component the issue affects and its version number. e.g., V12 RF board, Teensy output audio.

**Desktop environment (if relevant for error):**
 - OS: [e.g. Windows]
 - Arduino IDE version [e.g. 2.3.3]

**Additional context**
Add any other context about the problem here.

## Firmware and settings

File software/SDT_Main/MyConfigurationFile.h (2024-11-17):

//==============================================================
// This file is used to configure the specifics of your radio by 
// commenting/uncommenting/modifying particular #define statements
// to select which hardware you installed and any modifications to
// their addresses. You can also select which extra software capa-
// bilities you want to include in the same way. If you need to re-
// map Teensy pins or change the operation of the front panel buttons
// please edit SDT.h
//==============================================================

//====================== Hardware selections ===================

// Select either V11 hardware or V12 hardware
//#define V11HWR   // Selectes Si5351 clock frequencies for the 4x frequency method           
#define V12HWR     // Selects the V12 BPF, K9HZ LPF, V12 RF control, and affects Si5351

#ifdef V12HWR
  // Set the I2C addresses of the LPF, BPF, and RF boards
  #define K9HZ_LPF_MCP23017_ADDR  0x25
  #define BPF_MCP23017_ADDR       0x24
  #define RF_MCP23017_ADDR        0x27

  // K9HZ LPF options
  // Uncomment the appropriate line below to select which power detection option 
  // you populated in the SWR meter
  #define K9HZ_LPF_SWR_LOG_AMP
  //#define K9HZ_LPF_SWR_DIODE

  // Uncomment the appropriate line below to select which detected power readout 
  // option you populated in the SWR meter
  #define K9HZ_LPF_SWR_AD7991
  //#define K9HZ_LPF_SWR_ANALOG
#endif //V12HWR

// You can't change the Si5351 address, but it sometimes differs from the default 
// of 0x60. Change it here if needed.
#define SI5351_BUS_BASE_ADDR    0x60

// Uncomment if using G0ORX or K9HZ MCP23017 Front Panel
#define G0ORX_FRONTPANEL

// Set the I2C addresses of the front panel board
#define G0ORX_PANEL_MCP23017_ADDR_1 0x20
#define G0ORX_PANEL_MCP23017_ADDR_2 0x21

// Pick one of the following encoder configurations
#define                           NORM_ENCODER                              // Leave as is UNLESS...
//#define                           FOURSQRP                                // ...you are using the 4 States QRP kit

//====================== Software selections ===================

// Uncomment to exclude BEARING and/or BODE code
//#define EXCLUDE_BEARING
//#define EXCLUDE_BODE

// Uncomment if using G0ORX Kenwood TS-2000 CAT interface
#define G0ORX_CAT

// G0ORX_AUDIO_DISPLAY draws a Time Domain plot of the Microphone when transmitting
#define G0ORX_AUDIO_DISPLAY

// Fast tune function on fine tune knob from Harry Brash GM3RVL
#define FAST_TUNE

//====================== User Specific Preferences =============

#define DEBUG 		                1                                         // Uncommented for debugging, comment out for normal use
#define DECODER_STATE							0						                              // 0 = off, 1 = on
#define DEFAULT_KEYER_WPM   			15                                        // Startup value for keyer wpm
#define FREQ_SEP_CHARACTER  			'.'					                              // Some may prefer period, space, or combo
#define MAP_FILE_NAME   					"Cincinnati.bmp"                          // Name you gave to BMP map file. Max is 50 chars
#define MY_LAT										39.07466                                  // Coordinates for QTH
#define MY_LON										-84.42677
#define MY_CALL										"AI6YM"                                   // Default max is 10 chars
#define MY_TIMEZONE          			"PST: "                                   // Default max is 10 chars
//DB2OO, 29-AUG-23: TIME_24H to display 24 hour times (Utility.cpp). If this is not defined 12h display will be used
#define TIME_24H                  1
//DB2OO, 29-AUG-23: ITU_REGION to determine band borders: Upper band limits on 80m (3.8MHz vs 4.0MhHz) and 40m (7.2MHz vs. 7.3MHz)
// #define ITU_REGION                1  //for Europe
#define ITU_REGION                  2   // for USA
//#define ITU_REGION    3   // Asia/Oceania
// DB2OO, 29.823:. Analog Signal on this pin will be used for an analog S-Meter (250uA full scale) connected via 10kOhm to this output. 1uF capacitor paralle to the S-Meter. --> Display.cpp. 
// This might conflict with other hardware modifications, that might use Pin 33 for a different purpose --> please check, before defining this
//#define HW_SMETER              33
// DB2OO, 30-AUG-23: with TCVSDR_SMETER (TCVSDR=Teensy Convolution SDR) defined the S-Meter bar will be consistent with the dBm value and it will not go over the box for S9+40+
#define TCVSDR_SMETER             1
//DB2OO, 10-SEP-23: TCXO_25MHZ defined sets the default EEPROMData.freqCorrectionFactor = 0, as the TCXO is supposed to deliver 25.00000MHz
//#define TCXO_25MHZ                1

#define PADDLE_FLIP								0						                              // 0 = right paddle = DAH, 1 = DIT
#define STRAIGHT_KEY_OR_PADDLES		0						                              // 0 = straight, 1 = paddles
#define SDCARD_MESSAGE_LENGTH     3000L                                     // The number of milliseconds to leave error message on screen
//#define SD_CARD_PRESENT         0                                         //   JJP  7/18/23

//====================== System specific ===============
#define CURRENT_FREQ_A            7200000                                   // VFO_A
#define CURRENT_FREQ_B            7030000                                   // VFO_B
#define DEFAULTFREQINCREMENT 		  4                                         // Default: (10, 50, 100, 250, 1000, 10000Hz)
#define DEFAULT_POWER_LEVEL       10                                        // Startup power level. Probably 20 for most people
#define FAST_TUNE_INCREMENT    	  1			 		                                // Default from above for fine tune
#define SPLASH_DELAY              1000L                                     // How long to show Splash screen. Use 1000 for testing, 4000 normally
#define BIT_DELAY_LONG            10000L                                    // How long to show BIT screen with errors
#define BIT_DELAY_SHORT           1000L                                     // How long to show BIT screen when no error
#define STARTUP_BAND        			BAND_40M                                  // This is the 40M band. see around line 575 in SDT.h // G0ORX changed from 1

#define CENTER_SCREEN_X           400
#define CENTER_SCREEN_Y           245
#define IMAGE_CORNER_X            190                                       // ImageWidth = 378 Therefore 800 - 378 = 422 / 2 = 211
#define IMAGE_CORNER_Y            40                                        // ImageHeight = 302 Therefore 480 - 302 = 178 / 2 = 89
#define RAY_LENGTH                190

//=========== Applying hardware/software selections ============

// Set multiplication factors for your QSD and QSE boards.
#ifdef NORM_ENCODER
  #define MASTER_CLK_MULT_RX 2
  #define MASTER_CLK_MULT_TX 2  
#else
  #define MASTER_CLK_MULT_RX 4
  #define MASTER_CLK_MULT_TX 4
#endif 

#if defined(G0ORX_FRONTPANEL)
#include "G0ORX_FrontPanel.h"
#endif // G0ORX_FRONTPANEL

#if defined(G0ORX_CAT)
#include "G0ORX_CAT.h"
#endif // G0ORX_CAT

#ifdef V12HWR
  #define K9HZ_LPF           // Selects the K9HZ LPF board
  #define V12BPF             // Selects the V12 BPF board
#endif //V12HWR

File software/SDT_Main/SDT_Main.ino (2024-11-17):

/*********************************************************************************************

  This comment block must appear in the load page (e.g., main() or setup()) in any source code
  that uses code presented as whole or part of the T41-EP source code.

  (c) Frank Dziock, DD4WH, 2020_05_8
  "TEENSY CONVOLUTION SDR" substantially modified by Jack Purdum, W8TEE, and Al Peter, AC8GY

  This software is made available under the GNU GPLv3 license agreement. If commercial use of this
  software is planned, we would appreciate it if the interested parties contact Jack Purdum, W8TEE, 
  and Al Peter, AC8GY.

  Any and all other uses, written or implied, by the GPLv3 license are forbidden without written 
  permission from from Jack Purdum, W8TEE, and Al Peter, AC8GY.

V050.2 10-17-26 Al Peter,AC8GY
  Extensively revised the Process2 File to allow Calibrate using the V12.6 hardware. This file is
  included as ProcessV12.cpp given the scope of its modifications.
    1. Requires the 12.6 version RF board with the Cal jumper installed
    2. Both Input and Output Attenuators must be installed and active.
    3. No external calble are required. Simply short the Cal jumpers during the Receive and Xmit I/Q calibration sessions.
    4. Calibration values are stored in EEPROM.

V050.1 10/17/24 Oliver King, KI3P
  1. Added support for V12 features:
  1.1 Shutdown routine
  1.2 K9HZ LPF board control (band select only)
  1.3 V12 BPF board control
  1.4 Teensy pin assignment changes
  1.5 Built-in test to check I2C connections on start
  2. Merged in John Melton G0ORX's changes for new band definitions, JSON, RF control

V050.0 7/4/24  Jack Purdum, W8TEE
  1. Sectivated SELECT button to end Bode Plot
  2. Removed a number of redundant variables and uncalled functions.
  3. Comment out manu Serial.print() calls that the user may want to restore, but not toggle with DEBUG
  4. Fixed minor bug in Bearing code
  FLASH: code:261352, data:127580, headers:8376   free for files:7729156
   RAM1: variables:244000, code:257272, padding:4872   free for local variables:18144
   RAM2: variables:377120  free for malloc/new:147168

V049.7_Bode_04_03_24 Al Peter AC8GY
  1. Added Bode plot Module to allow easy evaluation of T41 BP and LP Filters.
  2. Intended for plotting of frequency response of T41 Filters. 
  3. Frequency range 3.5MHz to over 50MHz
  4. V12 hardware only.
  5. Code changes marked as "//=================== AFP 03-30-24 V012 Bode Plot"
  6. Most additions/changes are in a  new File "BodePlotter.cpp"
  7. Uses CW output as input to filter DUT.
  8. Connect DUT out directly to V12 RF board input
  9. Either use V12 input Attenuator set at -30dB or add external 30dB 50ohm atten. Take care to not overload RF input.
  10. Use full CW output  value for best SN.
  11. Disconnect RF PA and do not use other fT41 Filters during test.
  12. If testing T41 Filter boards, Band+ and Band- can be used to select bands.
  13. User buttons are employed as follows:
    * User1 (15) saves the current Bode plot as reference
    * User2 (16) toggles display of reference plot
    * User3 (17) toggles display of US Ham bands on plot
    * User4 (18) exits Bode routine.
  15. Encoders are used as follows:
    * FineTune changes the upper stop frequency
    * CenterTune changes the start frequency
    * Filter encoder activates ans moves the con-screen cursor
    * th=The Vol encoder sets the amount of offset of the plot displayed in 1dB increments. iseful for determining insertion loss.
  15. A Reference plot can be shown along with current plot. Useful for adjusting filter component values duing test.
  16. An on-screen cursor can be activated using the Filter encoder. Cursor values are display on screen.
  17. Plot frequency limits can be dynamically set during Bode Plot operation:
    * Center Tune Encoder changes the Bode plot Start frequency
    * Fine Tune encoder changes the stop frequency.
  18. The plot amplitude can be adjust using the Vol encoder. Increments are 1dB at a time.

v049.6a Mar 13, 2024 Jack Purdum, W8TEE
  1. Added ability to cancel out of Main Menu by pressing switch 18
v049.6 Mar 11, 2024 Jack Purdum, W8TEE
  1. Changed the menu system to use the Spectrum-Waterfall area of the display to show both Main and
     Secondary menu choices.
  2. Modified Menu/Filter encoder to work with new menu system
  3. Removed redundant buttons from switch matrix.
  4. Reordered switches to reflect new menu. This frees up 4 switches that can be reassigned by the user.
     The suggested switches are coded for the positions:
      
      Select    Memus     Band +

      Zoom      Display   Band -
                 Reset

      Mode      Demod     Main
                        Increment

      Noise     Notch   Fine Tune  
                        Increment

      Filter      CW      User 1
      Adjust     Reset  

      User 2    User 3    User 4

  5. Expanded information in Info Window
  6. Fixed display code to reflect changes.
  FLASH: code:251344, data:127580, headers:9168   free for files:7738372
   RAM1: variables:206272, code:247272, padding:14872   free for local variables:55872
   RAM2: variables:368928  free for malloc/new:155360

V049.3 October XX, 2023 Greg Raven (KF5N)
  1. Fixed muting after calibration.
  2. Minor comment edits.
  3. Fixed mic compression bug which caused default to -15 dB.
  4. Added ITU Region 3.
  5. The transmit equalizer has a default profile based on Neville's testing for SSB voice.
  6. SSB transmit compression defaults changed to Neville's settings.
  7. Morse decode will print last character and then a space.

V049.2 October 16, 2023 Greg Raven (KF5N)
  1. Changed folder to SDT and file to SDT.ino.
  2. Mic compression indicator fixed.
  3. Updates to fix remaining paddle flip issues.
  4. Mic compressor fixes.
  5. CW sidetone adjustment via encoder.
  6. Changed volume control to logarithmic.
  7. Changed instances of currentBandA to currentBand in CW Excite.
  8. Removed Serial print statement.
  9. Removed Serial print statements from volume control.
 10. Increased audio memory to 450.
 11. Working sidetone adjust with encoder.
 12. Perfect log responding volume control for sidetone.
 13. Inserted G0ORX main loop efficiency improvement.  Si5351 CLK2 is now set to PLLB.
 14. John G0ORX AGC enhancements.
 15. AGC updates.
 16. Fixed minor problem with RX/TX indicator showing TX coming out of setup().
 17. Added defines for ITU_REGION and TIME24H for internationalization. (DB2OO)
 18. S-Meter bar aligned to dBm value (DB2OO)
 19. Fixed override of EEPROM defaults in EEPROMRead(). (DB2OO)
 20. Jack changed encoder pins for 4SQRP.
 21. Changed ENCODER3_ENCODER_A/B to FINETUNE_ENCODER_A/B.
 22. Updated SetBandRelay() function to toggle only necessary GPOs.
 23. Fixed receiver outage after sidetone adjust.  Sidetone default = 50.0
 24. S-Meter: added debug code and rfGainAllBands (DB2OO)
 25. Add additional debug info in DisplaydbM() (DB2OO)
 26. Removed attribute DMAMEM from audioSpectBuffer because it breaks the S-meter.
 27. Added Jack's code to change color of version when running 4SQRP.
 28. Deleted increment variable in Encoders.cpp.  Was causing a compile warning.
 29. ITU_REGION set to 2, TCXO_25MHZ undefined, DEBUG_SMETER undefined.
 30. Added comments to ITU_REGION.
 31. Updated changes list in SDT.ino.  Added macro to increment variable in Encoders.cpp to eliminate warning.

V049.1 Aug 21, 2023 Greg Raven (KF5N)
  1. Changed 3 instances of VFO_A to activeVFO in function ButtonFrequencyEntry().
  2. Added TxRxFreq = centerFreq to EEPROMRead() to fix frequency related bugs.
  3. Added clean-up code to CopySDtoEEPROM() in function EEPROMOptions().
  4. Fixes for calibration graphics.
  5. Changed 2 instances of currentFreqA to currentFreq in ResetTuning() function.
  6. Previous fix to CopySDToEEPROM() accidentally overwritten.  This puts it back.
  7. Reactivated text in Direct Frequency Entry.
  8. Replaced keyer symbolic constants with appropriate global variables.
  9. Removed call to CopyEEPROMToSD() from EEPROMStartup().
 10. Bypass paddle flip in the case of a straight key.
 11. Frequency overwrite, Bearing, exit, and Direct Entry updates.
 12. Fixed receive cal not saving, cal graphics, SSB power cal.
 13. Revised RX cal again because it was saving 1X zoom.
 14. Restored option for KD0RC switch matrix calibration code.
 15. A significant refactoring of calibration.
 16. Fix for keyer click-clack.
 17. Keyer lower limit 5 WPM.
 18. Decoder was modifying keyer WPM.

V049a Aug 06, 2023, 2023 Jack Purdum (W8TEE)
  1. Corrected paddle flip issue
  2. Made several changes to set sdCardPresent to the proper value when tested.
  3. Changed frequency display to account for new font.
  4. Raised the frequencies by 2 pixels as the new font made then display too low and affect band info
  5. If only 1 map file found, no longer asks you to pick. It selects automatically the one file.
  FLASH: code:244340, data:123488, headers:8996   free for files:7749640
   RAM1: variables:206304, code:240792, padding:21352   free for local variables:55840
   RAM2: variables:342944  free for malloc/new:181344

V049 Aug 03, 2023, 2023 Jack Purdum (W8TEE)
  1. Numerous UI and formating fixes
  FLASH: code:243636, data:123488, headers:8676   free for files:7750664
   RAM1: variables:206304, code:240088, padding:22056   free for local variables:55840
   RAM2: variables:342944  free for malloc/new:181344

V048g July 31, 2023 Jack Purdum (W8TEE)
  1. If you have multiple QTH files for the bearing feature, it did not clear screen properly. Fixed.
  2. CW filter graphics managed between mode, band, and VFO changes.
  3. Several tuning fixes by Greg (KF5N)
  FLASH: code:243572, data:123488, headers:8740   free for files:7750664
   RAM1: variables:206304, code:240024, padding:22120   free for local variables:55840
   RAM2: variables:342944  free for malloc/new:181344

V048e July 30, 2023 Jack Purdum (W8TEE)
  1. Really made EEPROMSaveDefaults2() the function to initialize the EEPROM struct
  2. Noise filters were not completely erased in all cases after a change. Fixed.
  3. Fixed overrun of spectrum floor if a negative number entered.
  4. If you have multiple QTH files for the bearing feature, it did not clear screen properly. Fixed.
  FLASH: code:246388, data:123488, headers:8996   free for files:7747592
   RAM1: variables:206304, code:242840, padding:19304   free for local variables:55840
   RAM2: variables:342944  free for malloc/new:181344

V048d July 29, 2023 Jack Purdum (W8TEE)
  1. Made EEPROMSaveDefaults2() the function to initialize the EEPROM struct
  FLASH: code:246260, data:123488, headers:9124   free for files:7747592
   RAM1: variables:206304, code:242712, padding:19432   free for local variables:55840
   RAM2: variables:342944  free for malloc/new:181344

V048c July 28, 2023 Jack Purdum (W8TEE)
  1. Removed string literals for EEPROM switch values from EEPROMToSD() function call.
  2. Reformatted the EEPROMShow() output.
  FLASH: code:246388, data:123488, headers:8996   free for files:7747592
   RAM1: variables:206304, code:242840, padding:19304   free for local variables:55840
   RAM2: variables:342944  free for malloc/new:181344

V048b July 28, 2023 Jack Purdum (W8TEE)
  1. More bug fixes by Greg, mainly in the EEPROM code.
  FLASH: code:242804, data:123488, headers:8484   free for files:7751688
   RAM1: variables:206304, code:239256, padding:22888   free for local variables:55840
   RAM2: variables:342944  free for malloc/new:181344

V048a July 27, 2023 Jack Purdum (W8TEE)
  1. FIxed EEPROMWrite() bug.
  FLASH: code:249780, data:131680, headers:8676   free for files:7736328
   RAM1: variables:214496, code:246232, padding:15912   free for local variables:47648
   RAM2: variables:342944  free for malloc/new:181344

V048 July 26, 2023 Jack Purdum (W8TEE)
  1. Integrated Greg's display and encoder changes
  2. Fixed the EEPROM to SD copy routine
  FLASH: code:249780, data:131680, headers:8676   free for files:7736328
   RAM1: variables:214496, code:246232, padding:15912   free for local variables:47648
   RAM2: variables:342944  free for malloc/new:181344
  
V047k July 22, 2023 Greg KF5N
  1. Update to calibration for improved button response.
  2. Added additional improvements for audio quality.
  3. Added user settable noise floor by band feature.
  4. Implemented fix for VFO relay switching bug.
  5. Fixed EEPROM so separator character displays correctly on EEPROM/SD dump
  FLASH: code:239700, data:131680, headers:8516   free for files:7746568
   RAM1: variables:214496, code:236152, padding:25992   free for local variables:47648
   RAM2: variables:342944  free for malloc/new:181344  
   
V047i July 18, 2023 Jack Purdum (W8TEE)
  1. Removed SD_CARD_PRESENT and set global sdCardPresent by call to SDPresentCheck() 
  FLASH: code:237972, data:134128, headers:8820   free for files:7745544
   RAM1: variables:214496, code:234424, padding:27720   free for local variables:47648
   RAM2: variables:342944  free for malloc/new:181344

V047h July 17, 2023 Jack Purdum (W8TEE)
  1. EEPROM Cancel option was not shown on secondary menu.
  2. currentFrreqA and currentFreqB now properly stored in EEPROM when Saved.
  FLASH: code:233556, data:132040, headers:9180   free for files:7751688
   RAM1: variables:212384, code:230008, padding:32136   free for local variables:49760
   RAM2: variables:342944  free for malloc/new:181344
  
V047g July 17, 2023 Jack Purdum (W8TEE)
  1. Move several constants to MyConfigurationFile.h and rearranged them
  2. Increased Splash delay to 4 seconds
  FLASH: code:233556, data:132040, headers:9180   free for files:7751688
   RAM1: variables:212384, code:230008, padding:32136   free for local variables:49760
   RAM2: variables:342944  free for malloc/new:181344

V047f July 15, 2023 Jack Purdum (W8TEE)
  1. Change ShowFrequency() and FormatFrequency() to properly align digits
  2. Fixed EEPROM sync indicator for main tune changes
  3. Commented clearScreen function call in DrawBandWidthIndicatorBar() to clean up audio. KF5N
  4. DMAMEM attribute added to TX equalizer buffers to free up stack space. KF5N
  5. Consolidated Si5351 start-up code into setup() function. KF5N
  6. Revised waterfall.  User needs to adjust noise level (pixels above axis) to just above bottom of spectrum display. KF5N
  FLASH: code:237076, data:134064, headers:8756   free for files:7746568
   RAM1: variables:228832, code:233528, padding:28616   free for local variables:33312
   RAM2: variables:328544  free for malloc/new:195744

Vo47e July 15, 2023 Jack Purdum (W8TEE)
  1. Changed the font to use the onboard font for frequency display
  2. Change SHowFrequency() and FormatFrequency() to accommodate new font.
  FLASH: code:237012, data:134064, headers:8820   free for files:7746568
   RAM1: variables:228832, code:233464, padding:28680   free for local variables:33312
   RAM2: variables:328544  free for malloc/new:195744
 
V047c July 14, 2023 Jack Purdum (W8TEE)
  1. Merged Greg's latest code with Jack's. The main difference is the calibration and bearing code, plus the new header file.
  2. Main tuning fixed
  3. Missing dB scale added back and prints correctly now
  FLASH: code:236820, data:134064, headers:9012   free for files:7746568
   RAM1: variables:228832, code:233272, padding:28872   free for local variables:33312
   RAM2: variables:328544  free for malloc/new:195744

V047b July 13, 2023 Jack Purdum (W8TEE)
  1. FIxed the "waterfall stripe" per Greg email.
  FLASH: code:232980, data:144160, headers:8900   free for files:7740424
   RAM1: variables:227808, code:229432, padding:32712   free for local variables:34336
   RAM2: variables:328544  free for malloc/new:195744
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
FASTRUN void loop()  // Replaced entire loop() with Greg's code  JJP  7/14/23
{
  int pushButtonSwitchIndex = -1;

  long ditTimerOff;  //AFP 09-22-22
  long dahTimerOn;

#if defined(G0ORX_CAT)
  CATSerialEvent();
#endif

  // KI3P: Check for signal to begin shutdown and perform shutdown routine if requested
  if (digitalRead(BEGIN_TEENSY_SHUTDOWN) == HIGH){
    ShutdownTeensy();
  }

  valPin = ReadSelectedPushButton();  // Poll UI push buttons
  if (valPin != BOGUS_PIN_READ) {     // If a button was pushed...

//    Serial.print("\nIn loop() top: valPin = ");
//    Serial.println(valPin);
    pushButtonSwitchIndex = ProcessButtonPress(valPin);  // Winner, winner...chicken dinner!
//    Serial.print("pushButtonSwitchIndex = ");
//    Serial.println(pushButtonSwitchIndex);
    ExecuteButtonPress(pushButtonSwitchIndex);
    //Serial.print("   mainMenuIndex = " );
    //Serial.print(mainMenuIndex);
    //Serial.print("   secondaryMenuIndex = " );
    //Serial.println(secondaryMenuIndex);
  }



  //  State detection
#if defined(G0ORX_FRONTPANEL) || defined(G0ORX_CAT)
  if (xmtMode == SSB_MODE && my_ptt == HIGH) radioState = SSB_RECEIVE_STATE;
  if (xmtMode == SSB_MODE && my_ptt == LOW) radioState = SSB_TRANSMIT_STATE;
#else
  if (xmtMode == SSB_MODE && digitalRead(PTT) == HIGH) radioState = SSB_RECEIVE_STATE;
  if (xmtMode == SSB_MODE && digitalRead(PTT) == LOW) radioState = SSB_TRANSMIT_STATE;
#endif // G0ORX_FRONTPANEL
  if (xmtMode == CW_MODE && (digitalRead(paddleDit) == HIGH && digitalRead(paddleDah) == HIGH)) radioState = CW_RECEIVE_STATE;  // Was using symbolic constants. Also changed in code below.  KF5N August 8, 2023
  if (xmtMode == CW_MODE && (digitalRead(paddleDit) == LOW && xmtMode == CW_MODE && keyType == 0)) radioState = CW_TRANSMIT_STRAIGHT_STATE;
  if (xmtMode == CW_MODE && (keyPressedOn == 1 && xmtMode == CW_MODE && keyType == 1)) radioState = CW_TRANSMIT_KEYER_STATE;
  if (lastState != radioState) {
    SetFreq();  // Update frequencies if the radio state has changed.
  }
  //lastState = radioState;  // G0ORX 01092023

  //  Begin radio state machines

  //  Begin SSB Mode state machine

  switch (radioState) {
    case (SSB_RECEIVE_STATE):
      if (lastState != radioState) {  // G0ORX 01092023
        #if !defined(V12HWR)
        digitalWrite(MUTE, LOW);      // KI3P, no MUTE function in V12
        #endif
        modeSelectInR.gain(0, 1);
        modeSelectInL.gain(0, 1);
        digitalWrite(RXTX, LOW);  //xmit off
        #ifdef V12HWR
        setBPFPath(BPF_IN_RX_PATH);
        currentRF_InAtten = RAtten[currentBand];
        SetRF_InAtten(currentRF_InAtten);
        #endif
        T41State = SSB_RECEIVE;
        xrState = RECEIVE_STATE;
        modeSelectInR.gain(0, 1);
        modeSelectInL.gain(0, 1);
        modeSelectInExR.gain(0, 0);
        modeSelectInExL.gain(0, 0);
        modeSelectOutL.gain(0, 1);
        modeSelectOutR.gain(0, 1);
        modeSelectOutL.gain(1, 0);
        modeSelectOutR.gain(1, 0);
        modeSelectOutExL.gain(0, 0);
        modeSelectOutExR.gain(0, 0);
        phaseLO = 0.0;
        barGraphUpdate = 0;
        if (keyPressedOn == 1) {
          return;
        }
        ShowTransmitReceiveStatus();
      }
      ShowSpectrum();
      break;
    case SSB_TRANSMIT_STATE:
      Q_in_L.end();  //Set up input Queues for transmit
      Q_in_R.end();
      Q_in_L_Ex.begin();
      Q_in_R_Ex.begin();
      comp1.setPreGain_dB(currentMicGain);
      comp2.setPreGain_dB(currentMicGain);
      if (compressorFlag == 1) {
        SetupMyCompressors(use_HP_filter, (float)currentMicThreshold, comp_ratio, attack_sec, release_sec);  // Cast currentMicThreshold to float.  KF5N, October 31, 2023
      } else {
        if (compressorFlag == 0) {
          SetupMyCompressors(use_HP_filter, 0.0, comp_ratio, 0.01, 0.01);
        }
      }
      xrState = TRANSMIT_STATE;
      // centerTuneFlag = 1;  Not required with revised tuning scheme.  KF5N July 22, 2023
      #if !defined(V12HWR)
      digitalWrite(MUTE, HIGH);  // KI3P, no MUTE function in V12
      #else
      digitalWrite(XMIT_MODE, XMIT_SSB); // KI3P, July 28, 2024
      setBPFPath(BPF_IN_TX_PATH);
      currentRF_OutAtten = XAttenSSB[currentBand] + getPowerLevelAdjustmentDB();
      if (currentRF_OutAtten > 63) currentRF_OutAtten = 63;
      if (currentRF_OutAtten < 0) currentRF_OutAtten = 0;
      SetRF_OutAtten(currentRF_OutAtten);
      #endif
      digitalWrite(RXTX, HIGH);  //xmit on
      xrState = TRANSMIT_STATE;
      modeSelectInR.gain(0, 0);
      modeSelectInL.gain(0, 0);
      modeSelectInExR.gain(0, 1);
      modeSelectInExL.gain(0, 1);
      modeSelectOutL.gain(0, 0);
      modeSelectOutR.gain(0, 0);
      modeSelectOutExL.gain(0, powerOutSSB[currentBand]);  //AFP 10-21-22
      modeSelectOutExR.gain(0, powerOutSSB[currentBand]);  //AFP 10-21-22
      ShowTransmitReceiveStatus();

#if defined(G0ORX_FRONTPANEL) || defined(G0ORX_CAT)
      while (my_ptt == LOW) {
#else
      while (digitalRead(PTT) == LOW) {
#endif // G0ORX_FRONTPANEL
        ExciterIQData();
#if defined(G0ORX_FRONTPANEL)
        ExecuteButtonPress(ProcessButtonPress(ReadSelectedPushButton()));
#endif // G0ORX_FRONTPANEL
#if defined(G0ORX_CAT)
        CATSerialEvent();
#endif // G0ORX_CAT
      }
      Q_in_L_Ex.end();  // End Transmit Queue
      Q_in_R_Ex.end();
      Q_in_L.begin();  // Start Receive Queue
      Q_in_R.begin();
      xrState = RECEIVE_STATE;
      break;
    default:
      break;
  }
  //======================  End SSB Mode =================

  // Begin CW Mode state machine
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

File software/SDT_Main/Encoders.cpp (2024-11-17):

#ifndef BEENHERE
#include "SDT.h"
#endif

#ifdef FAST_TUNE
// Fine frequency tune control with variable speed by Harry Brash GM3RVL
bool FastTune = true;    //  HMB
uint32_t FT_last_time;   // millis() of last fine tune step   HMB
bool FT_ON = false;      // In fast tunung mode HMB
int FT_step_counter = 0; // how many fast steps have there been continuously HMB
int last_FT_step_size = 1; // so can go back HMB
const unsigned long FT_on_ms = 30;  // time between FTsteps below which increases the step size
const unsigned long FT_cancel_ms = 400;  // time between steps above which FT is cancelled
const int FT_trig = 4;  // number of short steps to trigger fast tune,
const int FT_step = 500;  // Hz step in Fast Tune
unsigned long MS_temp;    // HMB
unsigned long FT_delay;   // HMB
#endif // FAST_TUNE

/*****
  Purpose: EncoderFilter

  Parameter list:
    void

  Return value;
    void
    Modified AFP21-12-15
*****/
void FilterSetSSB() {
  long filter_change;

  // SSB
  if (filter_pos != last_filter_pos) {
    tft.writeTo(L2);  // Clear layer 2.  KF5N July 31, 2023
    tft.clearMemory();
    if (xmtMode == CW_MODE) BandInformation();
    tft.fillRect((MAX_WATERFALL_WIDTH + SPECTRUM_LEFT_X) / 2 - filterWidth, SPECTRUM_TOP_Y + 17, filterWidth, SPECTRUM_HEIGHT - 20, RA8875_BLACK);  // Erase old filter background
    filter_change = (filter_pos - last_filter_pos);
    if (filter_change >= 1) {
      filterWidth--;
      if (filterWidth < 10)
        filterWidth = 10;
    }
    if (filter_change <= -1) {
      filterWidth++;
      if (filterWidth > 100)
        filterWidth = 50;
    }
    last_filter_pos = filter_pos;
    // =============  AFP 10-27-22
    switch (bands[currentBand].mode) {
      case DEMOD_LSB:
        if (switchFilterSideband == 0)  // "0" = normal, "1" means change opposite filter
        {
          bands[currentBand].FLoCut = bands[currentBand].FLoCut + filter_change * 50 * ENCODER_FACTOR;
          //fHiCutOld= bands[currentBand].FHiCut;
          FilterBandwidth();
        } else if (switchFilterSideband == 1) {
          //if (abs(bands[currentBand].FHiCut) < 500) {
          bands[currentBand].FHiCut = bands[currentBand].FHiCut + filter_change * 50 * ENCODER_FACTOR;
          fLoCutOld = bands[currentBand].FLoCut;
        }
        break;
      case DEMOD_USB:
        if (switchFilterSideband == 0) {
          bands[currentBand].FHiCut = bands[currentBand].FHiCut - filter_change * 50 * ENCODER_FACTOR;
          //bands[currentBand].FLoCut= fLoCutOld;
          FilterBandwidth();
        } else if (switchFilterSideband == 1) {
          bands[currentBand].FLoCut = bands[currentBand].FLoCut - filter_change * 50 * ENCODER_FACTOR;
          // bands[currentBand].FHiCut= fHiCutOld;
        }
        break;
      case DEMOD_AM:
        bands[currentBand].FHiCut = bands[currentBand].FHiCut - filter_change * 50 * ENCODER_FACTOR;
        bands[currentBand].FLoCut = -bands[currentBand].FHiCut;
        FilterBandwidth();
        InitFilterMask();
        break;
      case DEMOD_SAM:  // AFP 11-03-22
        bands[currentBand].FHiCut = bands[currentBand].FHiCut - filter_change * 50 * ENCODER_FACTOR;
        bands[currentBand].FLoCut = -bands[currentBand].FHiCut;
        FilterBandwidth();
        InitFilterMask();
        break;
    }
    // =============  AFP 10-27-22
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

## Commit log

2024-08-17 Initial commit of hardware files as used in manufacturing.
    [SMD_BOM.xlsx, SMD_BOM_Filter_FineTune.xlsx, SMD_BOM_Tune_Volume.xlsx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]
2024-09-03 Replacing K9HZ amplifier with updated AC8GY design, at the request of K9HZ.
    [20w_pa_diode_board.kicad_pcb, 20w_pa_diode_board.kicad_sch, SMD_BOM.xlsx]
2024-09-18 Initial commits of BPF test, i2c scan, and main software.
2024-09-30 Restored k9hz amp, without closed source materials.
    [20w_pa_diode_board.kicad_pcb, 20w_pa_diode_board.kicad_sch, SMD_BOM.xlsx]
2024-10-27 Adding draft of front panel.
    [front_panel.dxf]
2024-11-17 Updating main Teensy software for T41 SDT. Based on https://github.com/KI3P/SDTVer050.0/commit/2f7bccf308826ce5f91d40895a645f1f4040332b
2024-11-24 Initial commit of enclosure for T41 w/7" display.
    [front_panel.dxf]
2024-11-30 Adding powerpole mount.
    [Powerpole Panel Mount.f3d, Powerpole Panel Mount.stl]
2025-01-03 Adding print sheets for T41 enclosure.
